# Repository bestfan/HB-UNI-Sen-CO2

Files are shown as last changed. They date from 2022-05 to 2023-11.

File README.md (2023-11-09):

# HB-UNI-Sen-CO2

### CO2 Sensor for Homematic with STM32 or RP2040 pico

Inspired by the excellent work of [MHSteve](https://github.com/HMSteve/HB-UNI-Sen-CO2/blob/main/README.md) I enhanced his solution by the following features:
- Use of STM32 boards (Blue Pill or Maple Mini) or RP2040 pico board
- Compatibility with standard sensor casing (86x86 mm)
- Use of Winsen MH-Z19 CO2 Sensor instead of SCD30 as option
- Use of touch pad as config button
- Use of RGB LED for traffic light instead of red/green LED

Due to the missing battery support of the STM32 and RP2040 boards and the space restrictions I left out the rechargeable batteries which seems to be bearable for me, since a power supply is needed anyway.

Here you can see some photos how the assembled boards look like

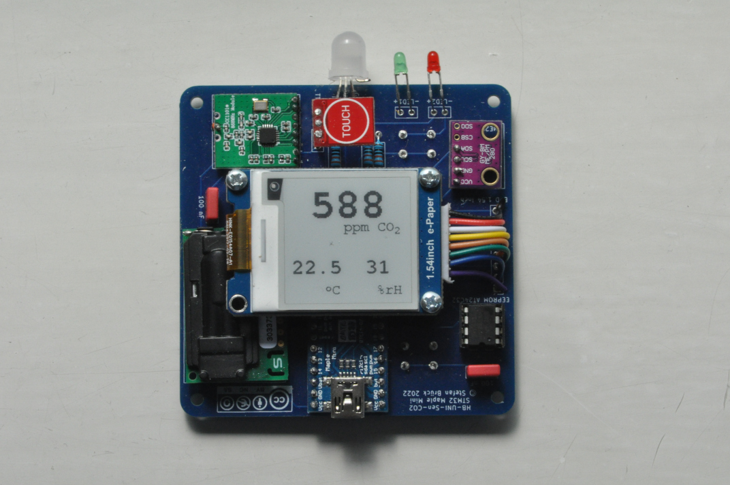
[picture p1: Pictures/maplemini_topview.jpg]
Top view of assembled PCB with Maple Mini


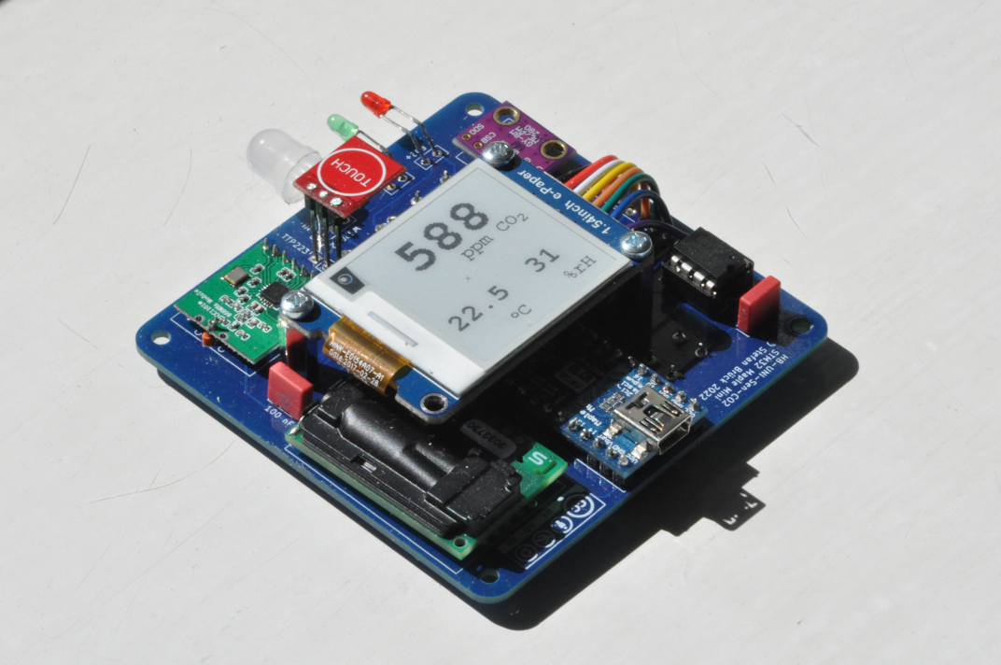
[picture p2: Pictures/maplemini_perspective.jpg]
Perspective view of assembled PCB with Maple Mini


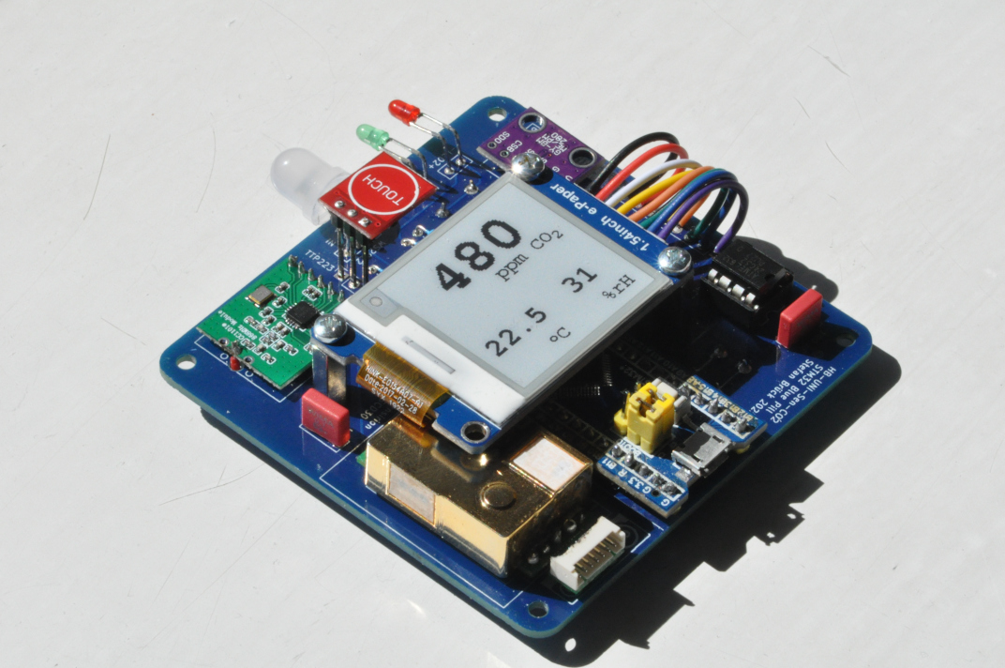
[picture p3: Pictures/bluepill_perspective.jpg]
Perspective view of assembled PCB with Blue Pill


And here how the sensor casing looks at the end

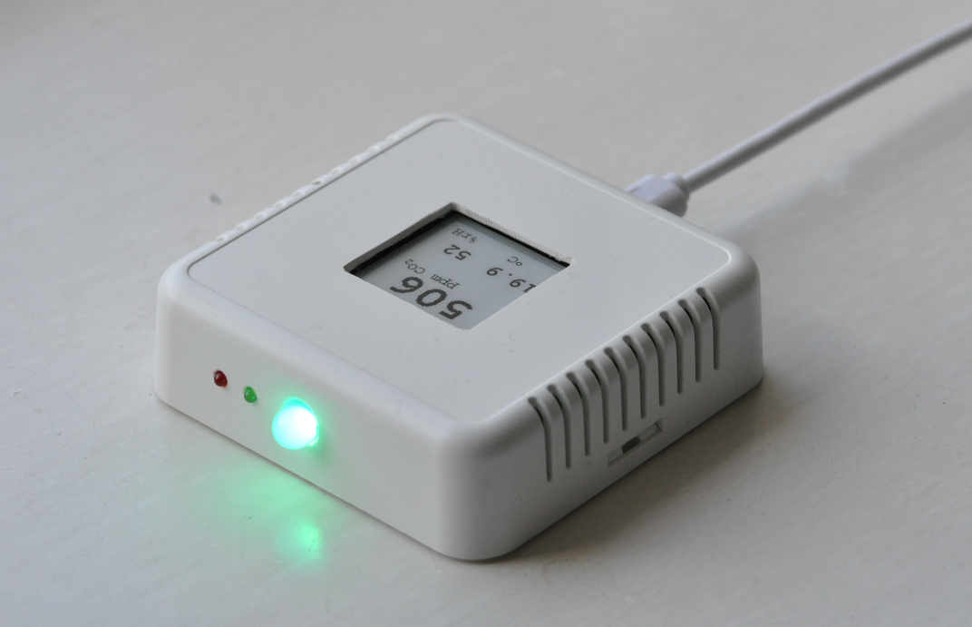
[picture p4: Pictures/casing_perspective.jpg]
Perspective view of assembled PCB with Blue Pill


## Software

### CCU Addon

Please, use the [Addon](https://github.com/HMSteve/SG-HB-Devices-Addon/raw/master/CCU_RM/sg-hb-devices-addon.tgz) of the original project. As stated there, the CO2 sensor ist supported from the version 1.23 onward. Due to the missing battery the voltage values shown in the CCU should be ignored.

### Sketch

In comparison to the original work, where the following libraries have been required
- AskSinPP
- EnableInterrupt
- LowPower
- SparkFun SCD30 Arduino Library
- Adafruit BME280 Library
- GxEPD (replaced by GxEPD2)
- Adafruit GFX

some additional libraries have to be applied
- MH-Z19, version 1.5.4 or newer
- bluepill_ws2812 (STM32)
- Adafruit NeoPixel (RP2040)
- GxEPD2 (STM32 and RP2040)
- OneWire (for use DS18B20 on RP2040 only), use of main version necessary.

If you decide to use a STM32 Blue Pill microcontroller, please, make sure that the STM32 bootloader is installed. It is possible to use the standard serial port to flash the software (or the bootloader), however the display won't work, because some of the connections are attached to debug pins.

## Credits

Special thanks to [MHSteve](https://github.com/HMSteve/HB-UNI-Sen-CO2/blob/main/README.md) for his high sophisticated work on the HB-UNI-Sen-CO2 Sensor. I also have to thank [der-pw](https://github.com/der-pw/hm_stm32_2ch_dimmer) for the very helpful STM32 example.

## Disclaimer

The usage of the published software and information is at your own risk and without any warranty.

## License

**Creative Commons BY-NC-SA**<br>
Give Credit, NonCommercial, ShareAlike

<br />This work is licensed under a <a rel="license" href="http://creativecommons.org/licenses/by-nc-sa/4.0/">Creative Commons Attribution-NonCommercial-ShareAlike 4.0 International License</a>.

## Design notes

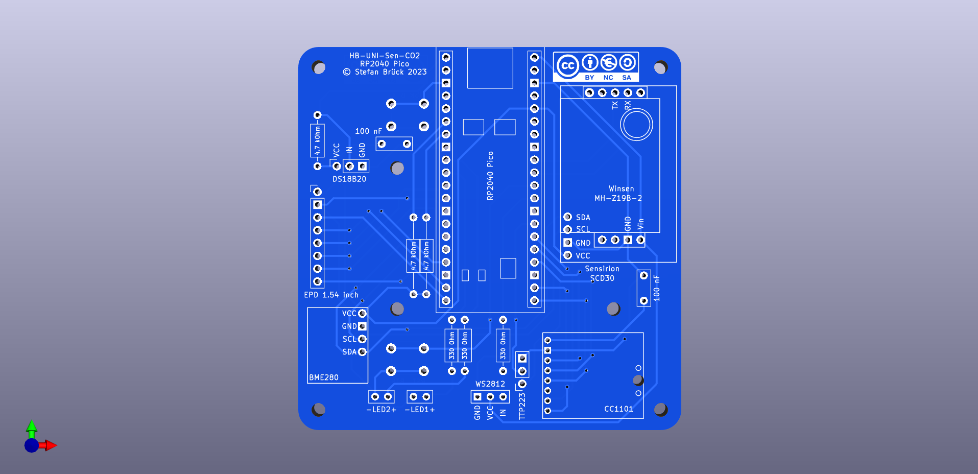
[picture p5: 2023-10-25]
Pictures/PCB_RP2040_front.png

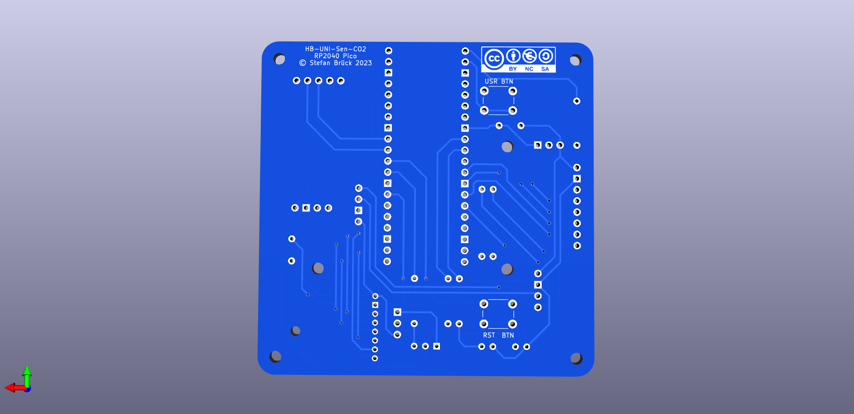
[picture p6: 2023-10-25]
Pictures/PCB_RP2040_back.png

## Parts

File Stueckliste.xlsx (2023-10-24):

Nummer | Beschreibung | Dimension | Anzahl | STM32 Blue Pill | STM32 Maple Mini | RP2040 Pico
1 | Schraube | M2.5x5mm | 10 | ● | ● | ●
2 | Abstandshülse Metall mit Gewinde (Innen/Außen) | M2.5x12mm | 4 | ● | ● | ●
3 | Abstandshülse Metall mit Gewinde (Innen) | M2.5x12mm | 3 | ● | ● | ●
4 | Widerstand, 0.5 W | 330 Ohm | 3 | ●**) | ●**) | ●**)
5 | Widerstand, 0.5 W | 4.7 kOhm | 2 oder 3 *) | ● | ● | ●
6 | Kondensator | RM=5mm, 100nF | 2 | ● | ● | ●
7 | Kontaktsensor TTP223 |  | 1 | ● | ● | ●
8 | RGB LED WS2812 | 8mm | 1 | ● | ● | ●
9 | LED grün | 3mm | 1 | ● | ● | ●
10 | LED rot | 3mm | 1 | ● | ● | ●
11 | Stiftleiste 2mm, gerade | 8 polig | 1 | ● | ● | ●
12 | Stiftleiste 2,54mm, gerade | 4 polig | 2 | ● | ● | ●
13 | Stiftleiste 2,54mm, gerade, 18mm Höhe | 3 polig | 1 | ● | ● | ●
14 | IC Sockel | 8 polig | 1 | ○ | ○ | —
15 | EEPROM | AT24C32 | 1 | ○ | ○ | —
16 | ePaper Display | 1.54 inch | 1 | ● | ● | ●
17 | BME280 |  | 1 | ○ | ○ | ○
18 | BMP280 |  | 1 | ○ | ○ | ○
19 | MH-Z19B or MH-Z19C (pin variante) |  | 1 | ○ | ○ | ○
20 | SCD30 |  | 1 | ○ | ○ | ○
21 | DS18B20 |  | 1 | — | — | ○
22 | Kurzhubtaster | 6x6, H=4.3mm | 2 | ● | ● | ●
23 | Sensorgehäuse CBRS01VWH | 86x86mm | 1 | ● | ● | ●
24 | STM32 Microcontroller Blue Pill |  | 1 | ● | — | —
25 | STM32 Microcontroller Maple Mini |  | 1 | — | ● | —
26 | RP2040 Pico Microcontroller |  | 1 | — | — | ●
27 | PCB |  | 1 | ● | ● | ●
● | notwendig
○ | optional
— | nicht relevant
*) | Bei der Nutzung des DS18B20 Temperatursensors wir ein zusätzlicher 4.7 kOhm Widerstand benötigt.
**) | Widerstand für WS2812 kann/muss ggf. weggelassen und überbrückt werden (insb. Für RP2040).

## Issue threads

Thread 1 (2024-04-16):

OneWire Libary funktionslos auf RP2040

MNieddu91, 2024-04-16:
Hallo bestfan,

erst einmal vielen Dank für deine Arbeit, meine 3 Sensoren arbeiten problemlos, allerdings muss ich aktuell auf die Verwendung des eingebauten DS18B20 verzichten, da die OneWire Libary scheinbar nicht auf RP2040 lauffähig ist.
Wenn ich Zeile 21 //#define useDS18X20 //use temperature sensor auskommentiere bleibt kann ich den Sketch zwar sauber uploaden, jedoch bleibt er dann beim anschalten des Gerätes bei in Zeile 32 in  Sens_DS18X20.h einfach stehen. TEST: DS18x20 init wird noch geprintet, aber dann hängt sich das device auf.

Test Sketche mit der OneWire Libary laufen auch nicht. Scheinbar gibt es hier tatsächlich Probleme mit OneWire und dem RP2040. Wenn ich einen Testscatch aus OneWire flashe, dann kriege ich keine Verbindung mehr über den COM Port auf dem RPi, vielleicht liegt hier auch schon das Problem. Welche Version von OneWire nutzt du denn ?

Es gibt eine angepasste Libary OneWireNG, welche bei mir funktioniert und mit Testsketch auch Ausgaben für den DS18B20 liefert. Leider reichen meine Kenntnisse jedoch nicht aus diese Anpassung selbst vorzunehmen.

Hast du ein geeignetes Setup zum testen? Schade wäre es, wenn ich nicht auf den verbauten TempSensor zurückgreifen kann.

Gerne kann ich dich auch beim debuggen unterstützen, sofern ich irgendwas testen soll.
Komme gerne einfach auf mich zu.

UPDATE: [Hier](https://github.com/PaulStoffregen/OneWire/issues/123) wird auch auf das Problem eingegangen und der Verweis zu OneWireNG aufgemacht.

Viele Grüße
Marco

MNieddu91, 2024-04-16:
Lösung:

Folgendes hat mir geholfen, nun erkennt er den DS18B20 https://forum.seeedstudio.com/t/ds18b20-temperature-sensor-issue/263525/5

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

Closed 2024-04-16.

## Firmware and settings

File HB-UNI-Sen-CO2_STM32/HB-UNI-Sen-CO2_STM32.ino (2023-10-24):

//- -----------------------------------------------------------------------------------------------------------------------
// AskSin++
// 2016-10-31 papa Creative Commons - http://creativecommons.org/licenses/by-nc-sa/3.0/de/
// 2019-02-28 jp112sdl (Creative Commons)
//- -----------------------------------------------------------------------------------------------------------------------
// 2020-11-07 CO2 Sensor, HMSteve (cc)
//- -----------------------------------------------------------------------------------------------------------------------
// 2022-04-25 CO2 Sensor on STM32 and other features, bestfan (cc)

#define NDEBUG   // disable all serial debug messages  

//#define EI_NOTEXTERNAL

#define SERIAL_OUTPUT  // data in JSONPATH format on serial line, use NDEBUG!
#define RGBLED

#define useMHZ19  //use MHZ19 CO2 sensor
//#define useSCD30  //use SCD30 CO2 sensor
#define useBME280 //use pressure sensor for compensation, in case MH-Z19 use also temperature and humidity

#define BAT_VOLT_LOW        22  // 2.2V for 2x Eneloop 
#define BAT_VOLT_CRITICAL   20  // 2.0V for 2x Eneloop

//#define USE_CC1101_ALT_FREQ

#if defined ARDUINO_ARCH_STM32F1
  #define STORAGEDRIVER at24cX<0x50,128,32>
//#define STORAGEDRIVER InternalEprom   // Alternative

  #define TICKS_PER_SECOND 500UL
  #define USE_HW_SERIAL
  #include <SPI.h>    // when we include SPI.h - we can use LibSPI class
  #include <Wire.h>   // for I2C access to EEPROM
  #include <EEPROM.h> // the EEPROM library contains Flash Access Methods
  #define BATT_SENSOR BatterySensor
  #if defined _BOARD_MAPLE_MINI_H_
    #define SPI1_NSS_PIN 7    //SPI_1 Chip Select pin is 7.
    #define SPI2_NSS_PIN 31   //SPI_2 Chip Select pin is 31.
  #else // Blue Pill
    #define SPI1_NSS_PIN PA4    //SPI_1 Chip Select pin is PA4.
    #define SPI2_NSS_PIN PB12   //SPI_2 Chip Select pin is PB12.
  #endif
  SPIClass SPI_2(2); //Create an instance of the SPI Class called SPI_2 that uses the 2nd SPI Port
#else
  #include <EnableInterrupt.h>
  #include <LowPower.h>
#endif

#include <AskSinPP.h>
#include <Register.h>
#include <MultiChannelDevice.h>
#ifndef ARDUINO_ARCH_STM32F1
  #include "sensors/tmBattery.h"  //SG: added from Tom's UniSensor project
#endif
#if defined useMHZ19
  #if defined ARDUINO_ARCH_STM32F1
    #define co2Serial Serial3  // serial3
  #else
    #define co2Serial (RX, TX)
  #endif
  #include "sensors/Sens_MHZ19.h"
#endif
#if defined useSCD30
  #include "sensors/Sens_SCD30.h"
#endif
#if defined useBME280
  #include "sensors/Sens_BME280.h"
#endif
#include "EPDisplay.h"


#if defined ARDUINO_ARCH_STM32F1 && defined RGBLED
  #include "bluepill_ws2812.h"
  bluepill_neopixel PIX;       // a string of pixels
  #define NUM_PIXELS 1     //   number of pixels in the string
  pixel string[NUM_PIXELS]; //   rgb data buffer
  #define RGBLED_PORT GPIOA //   pin string is connected to
  #if defined _BOARD_MAPLE_MINI_H_
    #define RGBLED_PIN  2
  #else
    #define RGBLED_PIN  8
  #endif
  #include "RgbLed.h"
#else
  #include "DuoLed.h"
#endif
#include "UserButton.h"

#if defined ARDUINO_ARCH_STM32F1
  #if defined _BOARD_MAPLE_MINI_H_
    #define CC1101_GDO0_PIN     3 // 
    #define CC1101_CS_PIN       7 // original PA4
    // CC1101 communication uses HW-SPI
    #define LED_PIN             11 // alternative 11 or LED_BUILTIN
    #define LED2_PIN            10
    #define DUOLED_GN_PIN       18 // suggested, not connected on PCB
    #define DUOLED_RT_PIN       19 // suggested, not connected on PCB
    #define CONFIG_BUTTON_PIN   8
    #define USER_BUTTON_PIN     17 // alternative 17 or 32 (build in)
    //  #define CC1101_PWR_SW_PIN   PA8
  #else
    // we use a BluePill
    #define CC1101_GDO0_PIN     PB0
    #define CC1101_CS_PIN       PA4 // original PA4
    // CC1101 communication uses HW-SPI
    #define LED_PIN             PB1  // aternative PB1 or LED_BUILTIN
    #define LED2_PIN            PA3
    #define DUOLED_GN_PIN       PB8 // suggested, not connected on PCB
    #define DUOLED_RT_PIN       PB9 // suggested, not connected on PCB
    #define CONFIG_BUTTON_PIN   PA1
    #define USER_BUTTON_PIN     PB5 
    //  #define CC1101_PWR_SW_PIN   PA8
  #endif
#else
  // Pin definitions Stephan's HB-UNI-Sen-CO2 Board v1.0
  #define CC1101_CS_PIN        4
  #define CC1101_GDO0_PIN      2
  #define CC1101_SCK_PIN       7 
  #define CC1101_MOSI_PIN      5 
  #define CC1101_MISO_PIN      6 
  #define LED_PIN             12              
  #define LED2_PIN            15
  #define DUOLED_GN_PIN       18
  #define DUOLED_RT_PIN       19
  #define CONFIG_BUTTON_PIN   14
  #define USER_BUTTON_PIN     13 
  #define CC1101_PWR_SW_PIN   27
#endif

#define PEERS_PER_CHANNEL 6
//tmBatteryLoad: sense pin A6, activation pin 26, Faktor = Rges/Rlow*1000, z.B. 10/30 Ohm, Faktor 40/10*1000 = 4000, 200ms Belastung vor Messung
// 1248p has 2.56V ARef, 328p has 1.1V ARef, so output needs to be scaled up
#ifndef ARDUINO_ARCH_STM32F1
  #define BATT_SENSOR tmBatteryLoad<A6, 26, (uint16_t)(4000.0*2.56/1.1), 200>
#endif


// all library classes are placed in the namespace 'as'
using namespace as;

// define all device properties
const struct DeviceInfo PROGMEM devinfo = {
  {0xf8, 0x22, 0x01},     // Device ID
  "CO2-000000",           // Device Serial
  {0xf8, 0x22},           // Device Model Indoor //orig 0xf1d1
  0x10,                   // Firmware Version
  as::DeviceType::THSensor, // Device Type
  {0x00, 0x01}            // Info Bytes
};




//Configure the used hardware
#if defined ARDUINO_ARCH_STM32F1
  typedef LibSPI<CC1101_CS_PIN> RadioSPI;
  typedef Radio<RadioSPI, CC1101_GDO0_PIN> RadioType;
#else
  typedef AvrSPI<CC1101_CS_PIN, CC1101_MOSI_PIN, CC1101_MISO_PIN, CC1101_SCK_PIN> SPIType;
  typedef Radio<SPIType, CC1101_GDO0_PIN> RadioType;
#endif
typedef StatusLed<LED_PIN> LedType;
typedef AskSin<LedType, BATT_SENSOR, RadioType> BaseHal;
typedef StatusLed<LED2_PIN> Led2Type;
#if defined RGBLED
  typedef RgbLed<RGBLED_PORT, RGBLED_PIN> RgbLedType;
#else
  typedef DuoLed<DUOLED_GN_PIN, DUOLED_RT_PIN> DuoLedType;
#endif


class Hal : public BaseHal {
  public:
    void init (const HMID& id) {
      BaseHal::init(id);
#ifdef USE_CC1101_ALT_FREQ
      radio.initReg(CC1101_FREQ2, 0x21);
      radio.initReg(CC1101_FREQ1, 0x65);
      radio.initReg(CC1101_FREQ0, 0xE2);
      //0x216572 868.303 MHz
#endif
// measure battery every a*b*c seconds
      battery.init(seconds2ticks(60UL * 30 * 1), sysclock);  
      battery.low(BAT_VOLT_LOW);
      battery.critical(BAT_VOLT_CRITICAL);
    }

    bool runready () {
      return sysclock.runready() || BaseHal::runready();
    }
} hal;


DEFREGISTER(Reg0, MASTERID_REGS, DREG_LEDMODE, DREG_TRANSMITTRYMAX, 0x20, 0x21, 0x22, 0x23, 0x24)
class SensorList0 : public RegList0<Reg0> {
  public:
    SensorList0(uint16_t addr) : RegList0<Reg0>(addr) {}

    bool updIntervall (uint16_t value) const {
      return this->writeRegister(0x20, (value >> 8) & 0xff) && this->writeRegister(0x21, value & 0xff);
    }
    uint16_t updIntervall () const {
      return (this->readRegister(0x20, 0) << 8) + this->readRegister(0x21, 0);
    }
    
    bool altitude (uint16_t value) const {
      return this->writeRegister(0x22, (value >> 8) & 0xff) && this->writeRegister(0x23, value & 0xff);
    }
    uint16_t altitude () const {
      return (this->readRegister(0x22, 0) << 8) + this->readRegister(0x23, 0);
    }

    bool tempOffset10 (uint8_t value) const {
      return this->writeRegister(0x24, value & 0xff);
    }
    uint16_t tempOffset10 () const {
      return this->readRegister(0x24, 0);
    }    


    void defaults () {
      clear();
      ledMode(1);
      transmitDevTryMax(3);     
      updIntervall(60); //seconds
      altitude(94); //meters
      tempOffset10(0); //temperature offset for SCD30 calib: 15 means 1.5K
    }
};



DEFREGISTER(Reg1, 0x01, 0x02, 0x03, 0x04, 0x05, 0x06, 0x07)
class SensorList1 : public RegList1<Reg1> {
  public:
    SensorList1 (uint16_t addr) : RegList1<Reg1>(addr) {}

    bool co2CalibRef (uint16_t value) const {
      return this->writeRegister(0x01, (value >> 8) & 0xff) && this->writeRegister(0x02, value & 0xff);
    }
    
    uint16_t co2CalibRef () const {
      return (this->readRegister(0x01, 0) << 8) + this->readRegister(0x02, 0);
    }

    bool co2StateAmber (uint16_t value) const {
      return this->writeRegister(0x03, (value >> 8) & 0xff) && this->writeRegister(0x04, value & 0xff);
    }
    
    uint16_t co2StateAmber () const {
      return (this->readRegister(0x03, 0) << 8) + this->readRegister(0x04, 0);
    }

    bool co2StateRed (uint16_t value) const {
      return this->writeRegister(0x05, (value >> 8) & 0xff) && this->writeRegister(0x06, value & 0xff);
    }
    
    uint16_t co2StateRed () const {
      return (this->readRegister(0x05, 0) << 8) + this->readRegister(0x06, 0);
    }

    bool co2NoGreen (uint16_t value) const {
      return this->writeRegister(0x07, value & 0xff);
    }
    
    uint16_t co2NoGreen () const {
      return this->readRegister(0x07, 0);
    }    

    void defaults () {
      clear();
      co2CalibRef(410); //410ppm in fresh air
      co2StateAmber(1000);     
      co2StateRed(2000); 
      co2NoGreen(0);       
    }
};



class WeatherEventMsg : public Message {
  public:
    void init(uint8_t msgcnt, int16_t temp, uint8_t humidity, uint16_t pressureNN, uint16_t co2, uint16_t volt, bool batlow) {
      uint8_t t1 = (temp >> 8) & 0x7f;
      uint8_t t2 = temp & 0xff;
      if ( batlow == true ) {
        t1 |= 0x80; // set bat low bit
      }
      // BIDI|WKMEUP every 20th msg
      uint8_t flags = BCAST;
      if ((msgcnt % 20) == 1) {
          flags = BIDI | WKMEUP;
      }      
      // Message Length (first byte param.): 11 + payload. Max. payload: 17 Bytes (https://www.youtube.com/watch?v=uAyzimU60jw)
      Message::init(18, msgcnt, 0x70, flags, t1, t2);
      pload[0] = humidity & 0xff;
      pload[1] = (pressureNN >> 8) & 0xff;           
      pload[2] = pressureNN & 0xff;          
      pload[3] = (co2 >> 8) & 0xff;           
      pload[4] = co2 & 0xff;         
      pload[5] = (volt >>8) & 0xff;
      pload[6] = volt & 0xff;      
    }
};




class WeatherChannel : public Channel<Hal, SensorList1, EmptyList, List4, PEERS_PER_CHANNEL, SensorList0>, public Alarm {
    WeatherEventMsg     msg;
    bool                firstMsg = true;
    uint16_t            millis;
    uint16_t            pressureAmb = 1013; //mean pressure at sea level in hPa
    uint16_t            pressureNN = 0; //dummy value to be returned if no sensor measurement
    uint16_t            co2 = 0;
    int16_t             temp10 = 0;
    uint8_t             humidity = 0;
    RgbLedType          trafficLight; 
    bool                trafficLightEnabled = true;
    ePaperType          ePaper;
#if defined useSCD30
    Sens_SCD30          scd30;
#endif               
#if defined useMHZ19
    Sens_MHZ19          mhz19;
#endif               
#if defined useBME280
    Sens_BME280         bme280;
#endif       
       

  public:
    WeatherChannel () : Channel(), Alarm(10), millis(0) {}
    
    virtual ~WeatherChannel () {}

    virtual void trigger (__attribute__ ((unused)) AlarmClock& clock) {
      // reactivate for next measure
      tick = delay();
      clock.add(*this);

      // measure
      #if defined useBME280
        bme280.measure(this->device().getList0().altitude());
        pressureAmb = bme280.pressure()/10;
        pressureNN = bme280.pressureNN();
        #if defined useSCD30
          temp10 = scd30.temperature() - this->device().getList0().tempOffset10();
        #else
          temp10 = bme280.temperature()- this->device().getList0().tempOffset10();
          humidity = bme280.humidity();
        #endif
      #endif
      #if defined useSCD30
         scd30.measure(pressureAmb);
      #endif
      #if defined useMHZ19
         mhz19.measure();
      #endif
     
      // suppress potentially erranous first CO2 measurements after reset due to connecting charger
      if (!firstMsg) {
        #if defined useSCD30
          co2 = scd30.carbondioxide();
          temp10 = scd30.temperature() - this->device().getList0().tempOffset10();
          humidity = scd30.humidity();        
        #endif
        #if defined useMHZ19
          co2 = mhz19.carbondioxide();
          #if !defined useBME280
            temp10 = mhz19.temperature() - this->device().getList0().tempOffset10();
            humidity = 0;
          #endif        
        #endif          
        DPRINT("Temp x10 / Hum / PressureNN x10 / PressureAmb / Batt x10 / CO2 = ");
        DDEC(temp10 / 10);DPRINT(" / ");
        DDEC(humidity);DPRINT(" / ");
        DDEC(pressureNN);DPRINT(" / ");
        DDEC(pressureAmb);DPRINT(" / ");     
        DDEC(device().battery().current() / 10);DPRINT(" / ");
        DDECLN(co2);

        uint8_t msgcnt = device().nextcount();
        msg.init( msgcnt, temp10, humidity, pressureNN, co2, device().battery().current() / 10, device().battery().low());
        if (msg.flags() & Message::BCAST) 
        {
          device().broadcastEvent(msg, *this);
        }
        else
        {
          device().sendPeerEvent(msg, *this);
        }
        
        DisplayData.co2 = co2;
        DisplayData.temperature = temp10 / 10.0;
        DisplayData.humidity = humidity;   
        DisplayData.lowbatt = device().battery().low();    
        ePaper.mustUpdateDisplay(true);
        ePaper.setRefreshAlarm(500);
#if defined SERIAL_OUTPUT
        Serial.println("{\"sensor\":{\"temp\":" + String(temp10 / 10.0) + "\,\"pressureAmb\":" + String(pressureAmb) + "\,\"pressureNN\":" + String(pressureNN)  + "\,\"humidity\":" + String(humidity) + "\,\"CO2\":" + String(co2) + "}}" );
#endif        
        setTrafficLight();
      };
      firstMsg = false;
    }


    uint32_t delay () {
      return seconds2ticks(this->device().getList0().updIntervall());
    }
    
    void setup(Device<Hal, SensorList0>* dev, uint8_t number, uint16_t addr) {
      Channel::setup(dev, number, addr);
      
      #if defined useSCD30
        uint16_t scd30SamplingInterval = this->device().getList0().updIntervall() / 5;
        if (scd30SamplingInterval < 1) {scd30SamplingInterval = 1;}       
        if (scd30SamplingInterval > 30) {scd30SamplingInterval = 30;}
        DPRINT("SCD30 sampling interval : ");DDECLN(scd30SamplingInterval);
        scd30.init(device().getList0().altitude(), this->device().getList0().tempOffset10(), scd30SamplingInterval, false);
      #endif
      #if defined useMHZ19
        mhz19.init(true);
      #endif
      
      #if defined useBME280
        bme280.init();
      #endif
      
      trafficLight.init();
      
      sysclock.add(*this);
    }

    uint8_t status () const {
      return 0;
    }

    uint8_t flags () const {
      return 0;
    }

    #if defined useSCD30
    bool forceCalibSCD30()
    {
      return(scd30.setForcedRecalibrationFactor(this->getList1().co2CalibRef()));
    }


    bool setSCD30SamplingInterval()
    {
      uint16_t scd30SamplingInterval = this->device().getList0().updIntervall() / 5;
      if (scd30SamplingInterval < 1) {scd30SamplingInterval = 1;}      
      if (scd30SamplingInterval > 30) {scd30SamplingInterval = 30;}
      return(scd30.setSamplingInterval(scd30SamplingInterval));
    }


    bool setMHZ19SamplingInterval()
    {
      uint16_t scd30SamplingInterval = this->device().getList0().updIntervall() / 5;
      if (scd30SamplingInterval < 1) {scd30SamplingInterval = 1;}      
      if (scd30SamplingInterval > 30) {scd30SamplingInterval = 30;}
      return(scd30.setSamplingInterval(scd30SamplingInterval));
    }


    void stopSCD30()
    {
      scd30.stop_measurements();   
    }
    #endif

    
    #if defined useMHZ19
    bool forceCalibMHZ19()
    {
      return(mhz19.setForcedRecalibrationFactor(this->getList1().co2CalibRef()));
    }


/*    bool setMHZ19SamplingInterval()
    {
      uint16_t mhz19SamplingInterval = this->device().getList0().updIntervall() / 5;
      if (mhz19SamplingInterval < 1) {mhz19SamplingInterval = 1;}      
      if (mhz19SamplingInterval > 30) {mhz19SamplingInterval = 30;}
      return(mhz19.setSamplingInterval(mhz19SamplingInterval));
    }*/


    void stopMHZ19()
    {
      mhz19.stop_measurements();   
    }
    #endif


    void setTrafficLight()
    {
      DPRINT("setTrafficLight");
      if (trafficLightEnabled)
      {
        if ((co2 <= this->getList1().co2StateAmber()) and (this->getList1().co2NoGreen())) trafficLight.setOff(&string[0]);
        if ((co2 <= this->getList1().co2StateAmber()) and !(this->getList1().co2NoGreen())) trafficLight.setGreen(&string[0]);
        if ((co2 > this->getList1().co2StateAmber()) and (co2 <= this->getList1().co2StateRed())) trafficLight.setAmber(&string[0]);
        if (co2 > this->getList1().co2StateRed()) trafficLight.setRed(&string[0]);
      }
      else
      {
        trafficLight.setOff(&string[0]);
      }
      PIX.paint( string[0].bytes, NUM_PIXELS, RGBLED_PORT, RGBLED_PIN );
    }

    bool toggleTrafficLight()
    {
      trafficLightEnabled = !trafficLightEnabled;
      setTrafficLight();
      return(trafficLightEnabled);
    }
};




class SensChannelDevice : public MultiChannelDevice<Hal, WeatherChannel, 1, SensorList0> {
  public:
    typedef MultiChannelDevice<Hal, WeatherChannel, 1, SensorList0> TSDevice;
    Led2Type    led2;
    
    SensChannelDevice(const DeviceInfo& info, uint16_t addr) : TSDevice(info, addr) 
    {
      led2.init();
    }
    
    virtual ~SensChannelDevice () {}

    virtual void configChanged () {
      TSDevice::configChanged();
    #if defined useSCD30
      this->channel(0).setSCD30SamplingInterval();
    #endif
    #if defined useMHZ19
//      this->channel(0).setMHZ19SamplingInterval();
    #endif
      DPRINTLN("* Config Changed       : List0");
      DPRINT(F("* LED Mode             : ")); DDECLN(this->getList0().ledMode());    
      DPRINT(F("* Sendeversuche        : ")); DDECLN(this->getList0().transmitDevTryMax());                   
      DPRINT(F("* SENDEINTERVALL       : ")); DDECLN(this->getList0().updIntervall());
      DPRINT(F("* Hoehe ueber NN       : ")); DDECLN(this->getList0().altitude());
      DPRINT(F("* Temp Offset x10      : ")); DDECLN(this->getList0().tempOffset10());   
         
    }
};



SensChannelDevice sdev(devinfo, 0x20);
//ConfigButton<SensChannelDevice> cfgBtn(sdev);
myConfigButton<SensChannelDevice> cfgBtn(sdev);   // for use of TTP223 without using solder pad
UserButton<SensChannelDevice> usrBtn(sdev);


void setup () {
  #if defined useMHZ19
    co2Serial.begin(9600);
    delay(1000);
  #endif
  //SG: switch on MOSFET to power CC1101 and sensors
  #ifndef ARDUINO_ARCH_STM32F1
    pinMode(CC1101_PWR_SW_PIN, OUTPUT);
    digitalWrite (CC1101_PWR_SW_PIN, LOW);
  #endif
  //init ePaper display
  //display.init(); //not done here because v2 of Waveshare display draws about continuous 3mA via Reset pin
  display.init(115200, true, 10, false, SPI_2, SPISettings(4000000, MSBFIRST, SPI_MODE0));
  
  #if defined NDEBUG && defined SERIAL_OUTPUT
    Serial.begin(57600);
  #else
    DINIT(57600, ASKSIN_PLUS_PLUS_IDENTIFIER);
  #endif
  #if defined ARDUINO_ARCH_STM32F1
    Wire.begin();
  #endif
  DDEVINFO(sdev);
  sdev.init(hal);
  buttonISR(cfgBtn, CONFIG_BUTTON_PIN);
  buttonISR(usrBtn, USER_BUTTON_PIN);  
  sdev.initDone();
  DPRINT("List0 dump: "); sdev.getList0().dump();
//  display.init(57600);
//  display.init();
}


void loop() {
  bool worked = hal.runready();
  bool poll = sdev.pollRadio();
  if ( worked == false && poll == false ) {
    if (hal.battery.critical()) {
      // this call will never return
      DPRINTLN("!!!Shutting down due to critical battery voltage!!!");
      #if defined useSCD30
        sdev.channel(0).stopSCD30();
      #endif
      #if defined useMHZ19
        sdev.channel(0).stopMHZ19();           
      #endif
      //display.init();
      //display.drawPaged(EmptyBattDisplay,0);
      //wait a bit to let paged epd refresh finish
      //delay(5000);
#ifndef ARDUINO_ARCH_STM32F1
      pinMode(CC1101_PWR_SW_PIN, INPUT);
#endif
      hal.activity.sleepForever(hal);      
    }    
    // if nothing to do - go to sleep
#ifndef ARDUINO_ARCH_STM32F1
    hal.activity.savePower<Sleep<>>(hal)
#endif
  }
}

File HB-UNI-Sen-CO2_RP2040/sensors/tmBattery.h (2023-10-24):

//---------------------------------------------------------
// tmBattery
// 2019-05-14 Tom Major (Creative Commons)
// https://creativecommons.org/licenses/by-nc-sa/4.0/
// You are free to Share & Adapt under the following terms:
// Give Credit, NonCommercial, ShareAlike
// +++
// AskSin++ 2016-10-31 papa Creative Commons
//---------------------------------------------------------

#ifndef _TM_BATTERY_H_
#define _TM_BATTERY_H_

#include <Debug.h>
#include <AlarmClock.h>

#ifdef ARDUINO_ARCH_AVR

#define ADCMUX_ADCMASK ((1 << MUX3) | (1 << MUX2) | (1 << MUX1) | (1 << MUX0))
#define ADCMUX_REFMASK ((1 << REFS1) | (1 << REFS0))

#define ADCMUX_REF_AREF ((0 << REFS1) | (0 << REFS0))
#define ADCMUX_REF_AVCC ((0 << REFS1) | (1 << REFS0))
#define ADCMUX_REF_RESV ((1 << REFS1) | (0 << REFS0))
#define ADCMUX_REF_VBG ((1 << REFS1) | (1 << REFS0))

#if defined(__AVR_ATmega32U4__) || defined(__AVR_ATmega1280__) || defined(__AVR_ATmega2560__) || defined(__AVR_ATmega644P__)                         \
    || defined(__AVR_ATmega1284P__)
#define ADCMUX_ADC_VBG ((1 << MUX4) | (1 << MUX3) | (1 << MUX2) | (1 << MUX1) | (0 << MUX0))
#else
#define ADCMUX_ADC_VBG ((1 << MUX3) | (1 << MUX2) | (1 << MUX1) | (0 << MUX0))
#endif
#else
#error INVALID ARCHITEKTURE
#endif

namespace as {

//---------------------------------------------------------
class tmBattery : public Alarm {
    uint8_t  m_Low, m_Critical;
    uint16_t m_LastValue;
    uint32_t m_Period;

public:
    tmBattery()
        : Alarm(0)
        , m_Low(0)
        , m_Critical(0)
        , m_LastValue(0)
        , m_Period(0)
    {
    }
    virtual ~tmBattery() {}

    virtual void trigger(AlarmClock& clock)
    {
        m_LastValue = voltage();
        tick        = m_Period;
        clock.add(*this);
    }

    uint16_t current() const { return m_LastValue; }

    bool critical() const
    {
        return ((m_LastValue / 100) < m_Critical);    // low/critical values have to be in default AskSinPP 100mV resolution
    }

    void critical(uint8_t value)
    {
        m_Critical = value;
        DPRINT(F("Battery set crit: "));
        DDECLN(m_Critical);
    }

    bool low() const { return ((m_LastValue / 100) < m_Low); }    // low/critical values have to be in default AskSinPP 100mV resolution

    void low(uint8_t value)
    {
        m_Low = value;
        DPRINT(F("Battery set low:  "));
        DDECLN(m_Low);
    }

    void init(uint32_t period, AlarmClock& clock)
    {
        // enable ADC, prescaler 128 = 62.5kHz ADC clock @8MHz (range 50..1000 kHz)
        ADCSRA      = (1 << ADEN) | (1 << ADPS2) | (1 << ADPS1) | (1 << ADPS0);
        ADCSRB      = 0;
        m_LastValue = voltage();
        m_Period    = period;
        tick        = m_Period;
        clock.add(*this);
    }

    void setIdle() {}
    void unsetIdle() {}

protected:
    uint16_t measure(uint16_t preDelayTime)
    {
        delay(preDelayTime);
        // messure 4 times
        uint16_t adc = 0;
        for (int i = 0; i < 4; i++) {
            ADCSRA |= (1 << ADSC);    // start conversion
            uint8_t timeout = 50;
            while (ADCSRA & (1 << ADSC)) {
                delayMicroseconds(10);
                timeout--;
                if (timeout == 0) {
                    return 0;
                }
            }
            adc += (ADC & 0x3FF);
            // DDECLN(ADC);
        }
        if ((adc & 0x03) >= 2) {    // rounding
            return (adc >> 2) + 1;
        } else {
            return (adc >> 2);
        }
    }

private:
    virtual uint16_t voltage()
    {
        // setup reference and input each time, just in case other SW modules have changed this
        ADMUX &= ~(ADCMUX_REFMASK | ADCMUX_ADCMASK);
        //ADMUX |= ADCMUX_REF_AVCC;      // select AVCC as reference
        ADMUX |= ADCMUX_ADC_VBG;       // select bandgap as input
        uint16_t adc = measure(50);    // load CVref 100nF, 5*Tau = 25ms
        if (adc) {
            // read Bandgap against AVCC:
            // ADC = Vin * 1024 / Vref -> Vref = Vin * 1024 / ADC
            // -> AVcc = Vbg * 1024 / ADC
            uint32_t avcc = 1100UL * 1024 / adc;
            DPRINT(F("tmBattery Voltage: "));
            DDECLN(avcc);
            return (uint16_t)avcc;
        } else {
            DPRINT(F("tmBattery Error"));
            return 0;
        }
    }
};

//---------------------------------------------------------
template <uint8_t SENSPIN, uint8_t ACTIVATIONPIN, uint16_t FACTOR> class tmBatteryResDiv : public tmBattery {
    // FACTOR: Rges/Rlow*1000, z.B. Teiler 470k/100k, Faktor 570k/100k*1000 = 5700

public:
    tmBatteryResDiv()
        : tmBattery()
    {
    }
    virtual ~tmBatteryResDiv() {}

    void init(uint32_t period, AlarmClock& clock)
    {
        pinMode(ACTIVATIONPIN, INPUT);    // disable resistor divider
        pinMode(SENSPIN, INPUT);          // input
        digitalWrite(SENSPIN, LOW);       // pull-up off
        tmBattery::init(period, clock);
    }

private:
    virtual uint16_t voltage()
    {
        // setup reference and input each time, just in case other SW modules have changed this
        ADMUX &= ~(ADCMUX_REFMASK | ADCMUX_ADCMASK);
        ADMUX |= ADCMUX_REF_VBG;                 // select bandgap as reference
        ADMUX |= ((SENSPIN - PIN_A0) & 0x0F);    // select SensePin as input

        pinMode(ACTIVATIONPIN, OUTPUT);
        digitalWrite(ACTIVATIONPIN, LOW);         // enable resistor divider
        uint16_t adc = tmBattery::measure(50);    // load CVref 100nF, 5*Tau = 25ms
        pinMode(ACTIVATIONPIN, INPUT);            // disable resistor divider

        if (adc) {
            // read SensePin against Bandgap:
            // ADC = Vin * 1024 / Vref -> Vin = Vref * ADC / 1024 (* resistor factor)
            uint32_t vbat = 11UL * adc * FACTOR / 1024 / 10;
            //DPRINT("adc: ");
            //DDECLN(adc);
            DPRINT(F("tmBatteryResDiv Voltage: "));
            DDECLN(vbat);
            return (uint16_t)vbat;
        } else {
            DPRINT(F("tmBatteryResDiv Error"));
            return 0;
        }
    }
};

//---------------------------------------------------------
template <uint8_t SENSPIN, uint8_t ACTIVATIONPIN, uint16_t FACTOR, uint16_t LOADTIME> class tmBatteryLoad : public tmBattery {
    // FACTOR: Rges/Rlow*1000, z.B. Teiler 10/30 Ohm, Faktor 40/10*1000 = 4000
    uint16_t m_LoadTime;    // Zeit für Aktivierung der Last in ms, Range 0..2000ms
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

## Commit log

2022-05-15 PCB Pictures
    Front and back of PCB design for Blue Pill and Maple Mini.
2022-05-15 Update PCB pictures
2022-05-15 Create HB-UNI-Sen-CO2-STM32.ino
    based on https://github.com/HMSteve/HB-UNI-Sen-CO2/main/HB-UNI-Sen-CO2.ino
2022-05-15 Create Sens_MHZ19.h
    Functions for Winsen MH-Z19 CO2 Sensor.
2022-05-15 Upload sensor header files
    Header files take from
    https://github.com/HMSteve/HB-UNI-Sen-CO2/tree/main/Sensors
2022-05-16 Add files via upload
    Add photos of assembled boards
2022-05-17 Add files via upload
    Gerber files for STM32 MapleMini variant added
2022-12-19 Update HB-UNI-Sen-CO2-STM32.ino
    Type of variable "temp10" change from uint to int.
2023-01-15 Update Sens_MHZ19.h
    Implementation of calibration function call.
    Works similar to the SCD30, however no calibration value can be defined.
2023-01-16 Update Sens_MHZ19.h
    Modify return value of calibration function to (always) true.
2023-09-29 Rename HB-UNI-Sen-CO2-STM32.ino to HB-UNI-Sen-CO2_STM32/HB-UNI-Sen-CO2_STM32.ino
    move location
2023-09-29 move of sensor files
2023-09-29 move sensor files
2023-09-29 move sensor directory
2023-09-29 move sensor dir
2023-09-29 move of sensor directory
2023-10-24 Parts list added for all variants and options
    [Stueckliste.xlsx]
2023-10-24 Add sensor files for RP2040 Version
2023-10-24 Update README.md
    Documentation modified regarding use of GxEPD2 library also for STM32
2023-10-25 Add pictures of PCB for RP2040 variant
